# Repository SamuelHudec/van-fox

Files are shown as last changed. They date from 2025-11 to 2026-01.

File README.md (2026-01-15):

# VanFox 🦊  – Portable Air Quality Monitor for Camper Vans

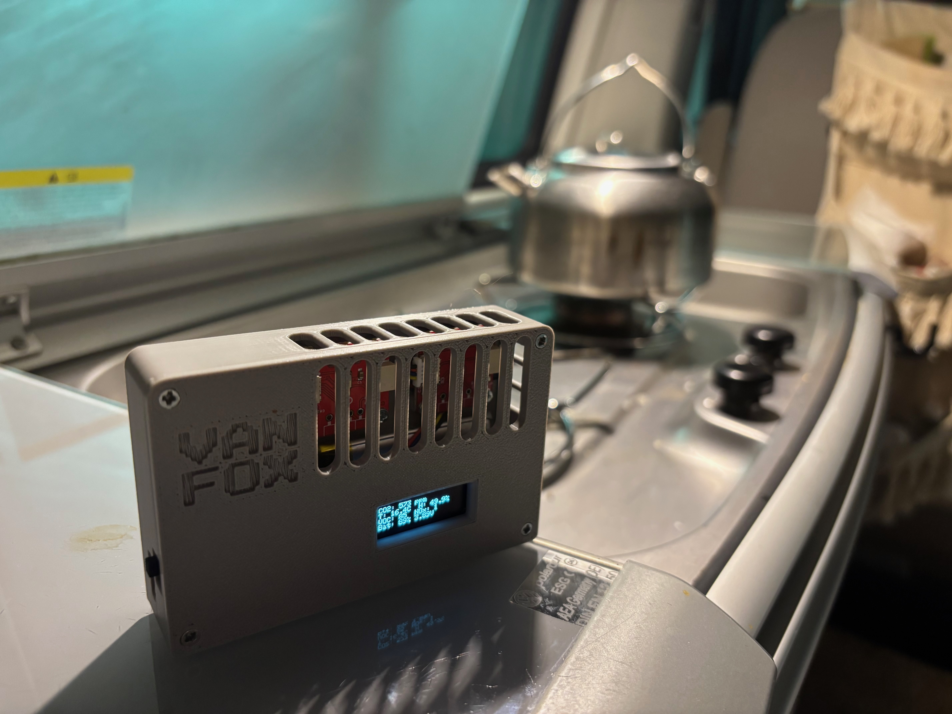
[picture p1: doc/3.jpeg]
preview


**VanFox** is a fully self-contained ESP32-C3-based air quality monitor designed for camper vans and Home Assistant.
It combines multiple environmental sensors, a motion-activated OLED display and gesture-based control.

VanFox is designed to be open, hackable and power-efficient, with a strong focus on real-world camper van usage. Thanks to the built-in battery, it can operate without external power — during off-grid camping, power outages, or when taken outside.

As a camper, I like when one device serves more than one purpose. VanFox can travel with you in your van, and when you are home, it can also be used as a stationary air quality monitor for your household.

## Assembly Guide

1. Purchase the components
	- ~298czk [ESP32 Dev Board](https://www.laskakit.cz/laskakit-microesp/)
	- ~448czk [CO2, temperature and humidity senzor](https://www.laskakit.cz/laskakit-stcc4-senzor-co2--teploty-a-vlhkosti-vzduchu/)
	- ~368czk [VOx and NOx senzor](https://www.laskakit.cz/laskakit-sgp41-voc-a-nox-senzor-kvality-ovzdusi/)
	- ~118czk [Battery](https://www.laskakit.cz/ehao-lipol-baterie-603048-900mah-3-7v/)
	- ~128czk [Oled Display](https://www.laskakit.cz/laskakit-oled-displej-128x32-0-91--i--c/)
	- ~198czk [Gyroscop](https://www.laskakit.cz/laskakit-bmi270-6-osy-gyroskop-a-akcelerometr/)
	- ~6czk [Buzz](https://www.laskakit.cz/aktivni-bzucak-3-3v/)
	- ~4czk [Switch](https://www.laskakit.cz/posuvny-prepinac-0-5a-50vdc/)
	- 4x~12czk [μŠup](https://www.laskakit.cz/--sup--stemma-qt--qwiic-jst-sh-4-pin-kabel-5cm/)
	- 10x M2 screws, I bougth a box and trimmed as needed

2. 3D print the enclosure from [3D](3D).
3. [Solder](doc/1.jpeg) the buzzer, switch, I²C cables, and battery to the ESP board. For I²C and battery, the pin placement is fixed by the board design. GPIO pins for the buzzer (GPIO 3) and switch (GPIO 2) were intentionally placed as far as possible from the USB-C connector, so the board fits properly into the enclosure.
4. Create a copy of `secrets_example.h` and rename it to `secrets.h`, then fill in all required values. 
5. Use Arduino IDE to flash the firmware to the device.
6. Home Assistant integration (optional)
	- Install the MQTT Broker add-on.
	- In the add-on configuration, add the device credentials `MQTT_NAME` and `MQTT_PASSWORD`.

There is also an option to use [ESPhome](SW/vanfox-esphome.yaml). However, gyroscope support is currently missing, which means, the display cannot be turned off automatically and will remain on continuously.

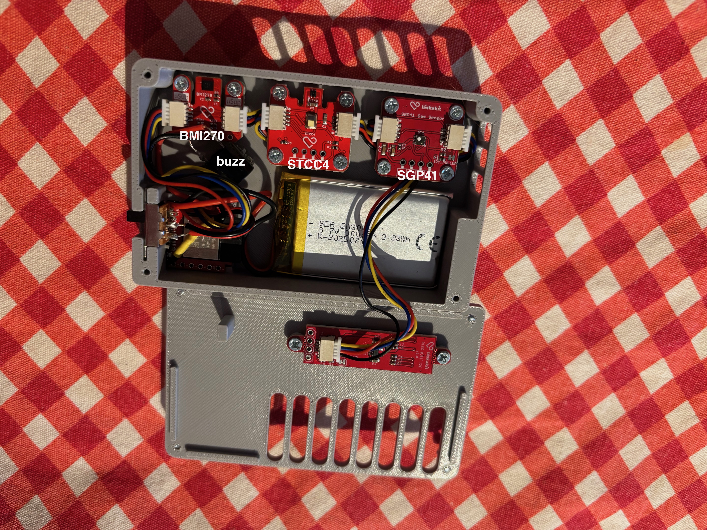
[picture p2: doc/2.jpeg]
preview2


## Operating Modes

### Power Modes (Switch-Controlled)

**Switch ON - Device Active:**
- **Home Mode** (WiFi available)
  - Connects to Home Assistant via MQTT
  - Sends sensor data
  - Display timeout: 30 seconds
- **Traveling Mode** (No WiFi)
  - Runs offline, no cloud connectivity
  - Light sleep between sensor reads (~90% power savings)
  - Display timeout: 10 seconds

**Switch OFF - Deep Sleep:**
- Ultra-low power (~10µA draw)
- Wakes every 60 seconds to check switch state
- Device boots when switch turned ON

### Display Modes (Available in Both Home & Traveling)

#### Air Quality Mode (Default)
Shows real-time environmental readings (Motion detection wakes display):
```
CO2: 412 ppm
T: 21.3°C  H: 45.7%
VOC: 102  NOx: 34
Bat: 100% (4.05V)
```

#### Level Mode (Digital Spirit Level)
Activated by **triple shake gesture**. Shows roll angle in degrees for vehicle leveling. Auto-returns to Air Quality Mode after 2 minutes

## TODO
- add boudaries for buzz

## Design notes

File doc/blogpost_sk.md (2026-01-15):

VanFox vznikol z mojej zvedavosti. S manželkou trávime veľa času v camper van a zaujímalo ma, ako sa v malom uzavretom priestore postupne zhoršuje kvalita vzduchu. Počas spánku stúpa CO₂ a pri varení sa zas hromadí vlhkosť a výpary oveľa skôr než doma v byte. Hotové riešenia možno existujú, ale ja som chcel niečo, na čom sa niečo nové naučím a bude to zábava. Navyše som chcel, aby zariadenie vedelo slúžiť nielen vo van-e, ale aj doma. Na moje prekvapenie aj manželka je nadšená.

Ako základ som si zvolil LaskaKit ESP32 mini, pretože mi v jednom riešení ponúka I²C konektivitu, nabíjanie batérie, jednoduché flashovanie kódu a možnosť reťaziť senzory pomocou uŠup konektorov. Postup zostavenia, zoznam komponentov aj 3D model krabičky som popísal na GitHube (odkaz nižšie).

Mašinka meria CO₂, teplotu, vlhkosť a kvalitu ovzdušia pomocou VOC a NOx indexov. Údaje zobrazuje na OLED displeji, ktorý sa rozsvieti len pri pohybe zariadenia. Vďaka integrovanej batérii ho možno používať ako prenosné zariadenie pri kempovaní v aute, stane atď. Zatiaľ čo doma je určený na trvalé napájanie, na cestách experimentujem s úspornými režimami a light sleep.

Gyroskop a akcelerometer som pôvodne pridal len kvôli tomu, aby sa displej rozsvietil pohybom bez potreby tlačidiel. Až neskôr som si uvedomil, že viem vyriešiť aj ďalší môj problém. Preto som pridal LEVEL MODE, digitálnu vodováhu aktivovanú trojitým zatrasením zariadenia.

Čo budeš potrebovať:
- [ESP32 dev board](https://www.laskakit.cz/laskakit-microesp/)
- [CO2, temperature and humidity senzor](https://www.laskakit.cz/laskakit-stcc4-senzor-co2--teploty-a-vlhkosti-vzduchu/)
- [VOx and NOx senzor](https://www.laskakit.cz/laskakit-sgp41-voc-a-nox-senzor-kvality-ovzdusi/)
- [Battery](https://www.laskakit.cz/ehao-lipol-baterie-603048-900mah-3-7v/)
- [Oled Display](https://www.laskakit.cz/laskakit-oled-displej-128x32-0-91--i--c/)
- [Gyroscop](https://www.laskakit.cz/laskakit-bmi270-6-osy-gyroskop-a-akcelerometr/)
- [Buzz](https://www.laskakit.cz/aktivni-bzucak-3-3v/)
- [Switch](https://www.laskakit.cz/posuvny-prepinac-0-5a-50vdc/)
- 4x [μŠup](https://www.laskakit.cz/--sup--stemma-qt--qwiic-jst-sh-4-pin-kabel-5cm/)
- 10x M2 šroub, ja som kupil celu krabičku a odštipal poldla potreby

Ako na to:
1. Vytlačte krabičku z [3D](https://github.com/SamuelHudec/van-fox/tree/main/3D).
2. Pripájkujte bzučiak, spínač, káble I²C a batériu k doske ESP. Pre I²C a batériu je umiestnenie pinov pevne stanovené dizajnom dosky. Piny GPIO pre bzučiak (GPIO 3) a spínač (GPIO 2) boli zámerne vybrané čo najďalej od konektora USB-C, aby doska správne zapadla do krytu.
3. Vytvorte kópiu súboru `secrets_example.h` a premenujte ho na `secrets.h`, potom vyplňte všetky požadované hodnoty. Nahrajte [kod](https://github.com/SamuelHudec/van-fox/blob/main/SW/vanfox/vanfox.ino).
4. Integrácia s Home Assistant (voliteľné)
- Nainštalujte doplnok MQTT Broker.
- V konfigurácii doplnku pridajte prihlasovacie údaje zariadenia `MQTT_NAME` a `MQTT_PASSWORD`.

Projekt je stále vo vývoji. Napríklad bzučiak je zapojený, ale zatiaľ sa v kóde nepoužíva. Pôvodný zámer bol zvukové upozornenie pri zhoršení kvality ovzdušia, no správanie ešte nemám úplne navrhnuté. Rovnako aj gestá, najmä triple-shake, by si zaslúžili ďalšie doladenie. V kóde je aj integrácia do Home Assistantu cez MQTT.

Ak máš nápady, chuť prispieť alebo niečo vylepšiť, som otvorený spolupráci. Napríklad, by sa prepínač dal napojiť priamo na prúd a namiesto deepsleep režimu, natvrdo vypnuť modul. Rád uvítam akékoľvek rady, či už po SW alebo HW stránke. Neboj sa rovno otvoriť PR s vylepšeniami alebo pokojne pridať aj vlastný file či rozšírenie.

https://github.com/SamuelHudec/van-fox

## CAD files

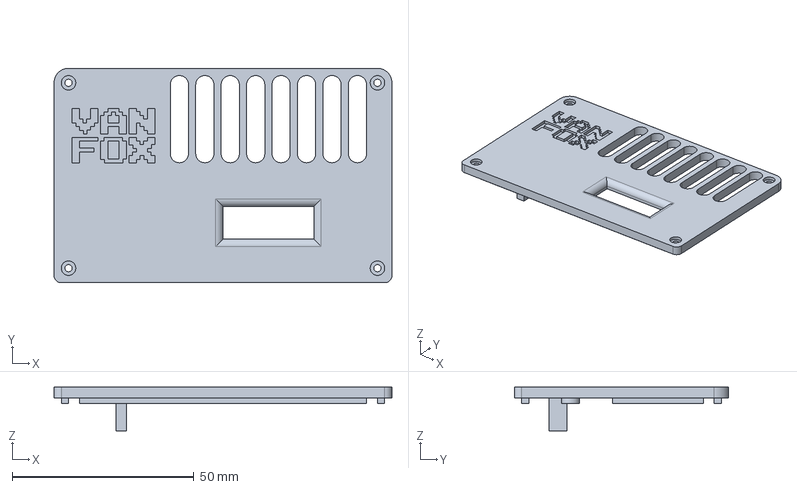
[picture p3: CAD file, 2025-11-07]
3D/hatch_V1.FCStd
93.0 x 59.0 x 12.0 mm

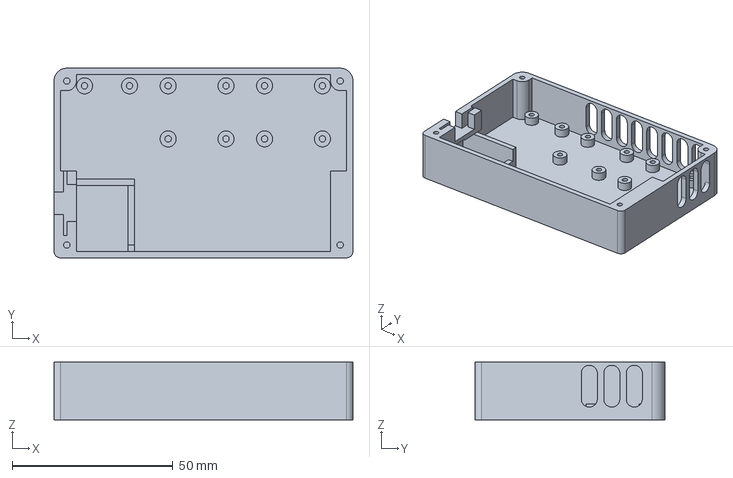
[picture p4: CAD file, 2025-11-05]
3D/box_V1.FCStd
93.0 x 59.0 x 18.0 mm

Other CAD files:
3D/box_V1.stl
3D/hatch_V1.stl

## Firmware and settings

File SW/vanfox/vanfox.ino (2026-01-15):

/*********************************************************************
 * VanFox – Portable Air Quality Monitor for Camper Vans
 * -----------------------------------------------------
 * Reads data from:
 *  - STCC4  (CO₂, Temperature, Humidity)
 *  - SGP41  (VOC, NOx)
 *  - BMI270 (Accelerometer, Gyroscope)
 *  - SSD1306 128x32 OLED Display
 *  - Battery voltage via ADC0 (LaskaKit MicroESP-C3 mini)
 *
 * Features:
 *  - Auto display sleep after inactivity
 *  - Triple-shake gesture to toggle LEVEL MODE
 *  - Level mode (digital spirit level)
 *  - Adaptive sensor/display update rates
 *********************************************************************/

#include <Wire.h>
#include <Adafruit_GFX.h>
#include <Adafruit_SSD1306.h>
#include <SensirionI2cStcc4.h>
#include <SensirionI2CSgp41.h>
#include <VOCGasIndexAlgorithm.h>
#include <NOxGasIndexAlgorithm.h>
#include "SparkFun_BMI270_Arduino_Library.h"
#include <WiFi.h>
#include <PubSubClient.h>
#include "esp_wifi.h"
#include "esp_bt.h"
#include "driver/gpio.h"
#include "driver/rtc_io.h"
#include "secrets.h"

// ===================================================================
// ---------------------- PINS CONFIG --------------------------------
#define SWITCH_PIN 2
#define BUZZ_PIN 3

// ===================================================================
// ---------------------- OLED CONFIG --------------------------------
#define SCREEN_WIDTH 128
#define SCREEN_HEIGHT 32
#define OLED_ADDR 0x3C
Adafruit_SSD1306 display(SCREEN_WIDTH, SCREEN_HEIGHT, &Wire, -1);

// ===================================================================
// ---------------------- SENSOR OBJECTS -----------------------------
SensirionI2cStcc4 stcc4;
SensirionI2CSgp41 sgp41;
VOCGasIndexAlgorithm vocAlgorithm;
NOxGasIndexAlgorithm noxAlgorithm;
BMI270 imu;

// ===================================================================
// ---------------------- WIFI & MQTT OBJECTS ------------------------
enum OperatingMode { MODE_TRAVELING, MODE_HOME };
OperatingMode currentMode = MODE_TRAVELING;
WiFiClient espClient;
PubSubClient mqtt(espClient);

// ===================================================================
// ---------------------- BATTERY CONFIG ------------------------------
#define PIN_BAT_ADC 0
#define BAT_DIVIDER_RATIO 1.7693877551  // (1M + 1.3M)

float readBatteryVoltage() {
  return analogReadMilliVolts(PIN_BAT_ADC) * BAT_DIVIDER_RATIO / 1000.0;
}

int voltageToPercent(float voltage) {
  voltage = constrain(voltage, 3.0, 4.0);
  return (int)((voltage - 3.0) * 100 / (4.0 - 3.0));
}

// ===================================================================
// ---------------------- LEVEL OFFSETS -------------------------------
const float ROLL_OFFSET  = 0.0;  // Calibration offset (adjust on level surface)

// ===================================================================
// ---------------------- GLOBAL VARIABLES ---------------------------
float co2_ppm = NAN, temperature_c = NAN, humidity_rh = NAN;
float voc_index = NAN, nox_index = NAN;
float battery_v = NAN;
int battery_p = 0;
bool charging = false;

bool displayOn = true;
bool gyroMode = false;
unsigned long lastModeSwitch = 0;

// ---------------------- TIMERS & PERIODS ---------------------------
const uint32_t MOTION_PERIOD_MS   = 100;    // IMU polling (shake + motion)
const uint32_t AIR_DISPLAY_MS     = 1000;   // redraw air screen
const uint32_t LEVEL_DISPLAY_MS   = 200;    // redraw level screen
const uint32_t AIR_SENSOR_READ_MS = 2000;   // SCD41 & SGP41 read interval
const uint32_t HOME_DISPLAY_TIMEOUT = 30000;       // 30s
const uint32_t TRAVELING_DISPLAY_TIMEOUT = 10000;  // 10s
const uint32_t HA_SEND_INTERVAL_MS = 300000;       // 5min
const uint32_t MQTT_RECONNECT_INTERVAL_MS = 60000; // 60s
const uint32_t DEEP_SLEEP_WAKEUP_SEC = 60;         // Wake every 60s to check switch

uint32_t t_motion = 0;
uint32_t t_air    = 0;
uint32_t t_level  = 0;
uint32_t t_air_sensor = 0;  // Replaces t_scd and t_sgp
uint32_t t_ha_send = 0;
uint32_t t_mqtt_reconnect = 0;

// ---------------------- ROBUST SHAKE DETECTION  ---------------------------
bool detectShake(float shakeIntensity) {
  static bool wasAbove = false;
  static unsigned long lastShake = 0;
  const float UPPER_THRESHOLD = 1.2;
  const float LOWER_THRESHOLD = 0.5;
  const int MIN_INTERVAL = 250;

  bool shakeDetected = false;

  if (!wasAbove && shakeIntensity > UPPER_THRESHOLD) {
    wasAbove = true;
  }

  if (wasAbove && shakeIntensity < LOWER_THRESHOLD) {
    wasAbove = false;
    unsigned long now = millis();
    if (now - lastShake > MIN_INTERVAL) {
      shakeDetected = true;
      lastShake = now;
    }
  }

  return shakeDetected;
}

// ===================================================================
// ---------------------- DEEP SLEEP FUNCTION ------------------------
void enterDeepSleep() {
  Serial.println("Switch OFF - entering deep sleep...");

  display.clearDisplay();
  display.setTextSize(1);
  display.setCursor(0, 10);
  display.println("Powering OFF...");
  display.println("Flip switch to wake");
  display.display();
  delay(2000);

  display.clearDisplay();
  display.display();

  // Configure timer wakeup: wake periodically to check switch state
  esp_sleep_enable_timer_wakeup(DEEP_SLEEP_WAKEUP_SEC * 1000000ULL);

  Serial.printf("Entering deep sleep (%ds wakeup)...\n", DEEP_SLEEP_WAKEUP_SEC);
  delay(100);
  esp_deep_sleep_start();
}

// ===================================================================
// ---------------------- SETUP --------------------------------------
void setup() {
  // --- Configure mode switch FIRST (before any other init) ---
  pinMode(SWITCH_PIN, INPUT_PULLUP);

  // Check if we woke from deep sleep with timer wakeup
  esp_sleep_wakeup_cause_t wakeup_reason = esp_sleep_get_wakeup_cause();

  if (wakeup_reason == ESP_SLEEP_WAKEUP_TIMER) {
    if (digitalRead(SWITCH_PIN) == LOW) {
      esp_sleep_enable_timer_wakeup(DEEP_SLEEP_WAKEUP_SEC * 1000000ULL);
      esp_deep_sleep_start();
    }
  }

  Serial.begin(115200);
  delay(1000);

  // --- Disable WiFi immediately to prevent auto-connect ---
  WiFi.persistent(false);
  WiFi.mode(WIFI_OFF);
  delay(100);

  // --- I2C Init ---
  Wire.begin(8, 10);   // SDA=8, SCL=10
  Wire.setClock(50000);

  // --- OLED Init ---
  if (!display.begin(SSD1306_SWITCHCAPVCC, OLED_ADDR)) {
    Serial.println("OLED not found!");
    while (true) delay(100);
  }
  display.clearDisplay();
  display.setTextColor(SSD1306_WHITE);
  display.setTextSize(1);
  display.println("VanFox Air Monitor");
  display.println("Initializing...");
  display.display();
  delay(1000);

  // ---------------- MODE SELECTION BASED ON SWITCH ----------------
  display.clearDisplay();
  display.setCursor(0, 0);
  display.println("VanFox Air Monitor");

  // Give WiFi hardware time to stabilize after boot
  delay(2000);

  bool switchOn = digitalRead(SWITCH_PIN) == HIGH;

  // If switch is OFF, enter deep sleep immediately (no sensor init needed)
  if (!switchOn) {
    display.println("Switch OFF - Power");
    display.println("saving mode");
    display.display();
    delay(1000);
    enterDeepSleep();
  }

  if (switchOn) {
    // Switch ON - Try HOME mode with WiFi
    Serial.println("Switch ON - attempting HOME mode");
    display.println("Switch: HOME Mode");
    display.println("Waiting 10s...");
    display.println("(router rate limit)");
    display.display();

    // Wait to let router rate-limit expire
    delay(10000);  // 10 second delay before WiFi attempt

    display.clearDisplay();
    display.setCursor(0, 0);
    display.println("Checking WiFi...");
    display.display();

    if (initWiFi()) {
      currentMode = MODE_HOME;
      display.println("WiFi Connected!");
      display.printf("IP: %s\n", WiFi.localIP().toString().c_str());
      display.display();
      delay(1000);

      if (initHomeAssistantAPI()) {
        display.println("HA: Connected");
      } else {
        display.println("HA: Failed (retry)");
      }
      display.display();
      delay(2000);
    } else {
      currentMode = MODE_TRAVELING;
      display.println("WiFi Failed!");
      display.println("Running offline");
      display.display();
      delay(2000);
    }
  }

  // ---------------- SENSOR INITIALIZATION ----------------
  bool scd_ok = false, sgp_ok = false, imu_ok = false;

  // --- STCC4 Init ---
  Serial.println("Initializing STCC4...");
  stcc4.begin(Wire, STCC4_I2C_ADDR_64);
  delay(500);
  stcc4.stopContinuousMeasurement();
  if (stcc4.startContinuousMeasurement() == 0) {
    scd_ok = true;  // Keep variable name for compatibility
    Serial.println("STCC4 ready.");
  } else {
    Serial.println("STCC4 not responding!");
  }

  // --- SGP41 Init ---
  Serial.println("Initializing SGP41...");
  sgp41.begin(Wire);
  delay(200);
  uint16_t rawVoc, rawNox;
  uint16_t dummyH = 0, dummyT = 0;
  if (sgp41.measureRawSignals(dummyH, dummyT, rawVoc, rawNox) == 0) {
    sgp_ok = true;
    Serial.println("SGP41 ready.");
  } else {
    Serial.println("SGP41 not responding!");
  }

  // --- BMI270 Init ---
  Serial.println("Initializing BMI270...");
  if (imu.beginI2C(0x68) == BMI2_OK) {
    imu_ok = true;
    Serial.println("BMI270 ready.");
  } else {
    Serial.println("BMI270 not detected!");
  }

  // ---------------- DISPLAY SENSOR STATUS ----------------
  display.clearDisplay();
  display.setCursor(0, 0);
  display.println("Sensor check:");
  display.printf("STCC4: %s\n", scd_ok ? "OK" : "FAIL");
  display.printf("SGP41: %s\n", sgp_ok ? "OK" : "FAIL");
  display.printf("BMI270: %s\n", imu_ok ? "OK" : "FAIL");

  if (scd_ok && sgp_ok && imu_ok)
    display.println("All sensors ready!");
  else
    display.println("Some sensors missing!");

  display.display();
  delay(2000);
}

// ===================================================================
// ---------------------- LOOP --------------------------------------
void loop() {
  uint32_t now = millis();

  // ============================================================
  // ------------------- MODE SWITCH CHECK ----------------------
  static uint32_t lastSwitchCheck = 0;
  static bool lastSwitchState = HIGH;

  if (now - lastSwitchCheck >= 2000) {
    lastSwitchCheck = now;
    bool currentSwitchState = digitalRead(SWITCH_PIN) == HIGH;

    // Detect switch change
    if (currentSwitchState != lastSwitchState) {
      lastSwitchState = currentSwitchState;

      if (currentSwitchState) {
        Serial.println("Switch ON - switching to HOME mode");

        display.clearDisplay();
        display.setTextSize(1);
        display.setCursor(0, 10);
        display.println("Switching to");
        display.println("HOME MODE...");
        display.display();
        delay(1000);

        if (initWiFi()) {
          currentMode = MODE_HOME;
          initHomeAssistantAPI();
          Serial.println("HOME mode activated");
        } else {
          Serial.println("WiFi failed, staying TRAVELING");
        }

      } else {
        enterDeepSleep();
      }
    }
  }

  // --- Air Quality Sensors (STCC4 + SGP41) ---
  if (now - t_air_sensor >= AIR_SENSOR_READ_MS) {
    t_air_sensor = now;

    // Read STCC4 (CO2, Temperature, Humidity)
    int16_t co2Raw;
    float temp, hum;
    uint16_t status;
    if (stcc4.readMeasurement(co2Raw, temp, hum, status) == 0) {
      co2_ppm = (float)co2Raw;  // Convert int16_t to float
      temperature_c = temp;
      humidity_rh = hum;
    }

    // Read SGP41 (VOC, NOx) - uses temp/humidity from STCC4 for compensation
    uint16_t compHumidity = (uint16_t)((humidity_rh * 65535) / 100);
    uint16_t compTemperature = (uint16_t)(((temperature_c + 45) * 65535) / 175);
    uint16_t rawVoc = 0, rawNox = 0;
    if (sgp41.measureRawSignals(compHumidity, compTemperature, rawVoc, rawNox) == 0) {
      voc_index = vocAlgorithm.process(rawVoc);
      nox_index = noxAlgorithm.process(rawNox);
    }
  }

  // --- Battery ---
  static float smoothBatteryV = 0.0;
  battery_v = readBatteryVoltage();
  smoothBatteryV = 0.9f * smoothBatteryV + 0.1f * battery_v;
  battery_p = voltageToPercent(smoothBatteryV);

  // ============================================================
  // ------------------- MQTT HANDLING (HOME MODE) --------------
  if (currentMode == MODE_HOME) {
    if (mqtt.connected()) {
      mqtt.loop();
      if (now - t_ha_send >= HA_SEND_INTERVAL_MS) {
        t_ha_send = now;
        sendDataToHomeAssistant();
      }
    } else {
      if (now - t_mqtt_reconnect >= MQTT_RECONNECT_INTERVAL_MS) {
        t_mqtt_reconnect = now;
        Serial.println("Reconnecting to MQTT...");
        if (WiFi.status() != WL_CONNECTED) {
          Serial.println("WiFi disconnected - reconnecting...");
          WiFi.disconnect();
          WiFi.begin(WIFI_SSID, WIFI_PASSWORD);

          unsigned long startAttempt = millis();
          while (WiFi.status() != WL_CONNECTED && millis() - startAttempt < 10000) {
            delay(500);
          }

          if (WiFi.status() != WL_CONNECTED) {
            Serial.println("WiFi reconnect failed");
            return;
          }
          Serial.println("WiFi reconnected!");
        }
        if (mqtt.connect("vanfox", "vanfox", "vanfox97411")) {
          Serial.println("MQTT reconnected");
          publishDiscoveryConfig();
        } else {
          Serial.print("MQTT reconnect failed, rc=");
          Serial.println(mqtt.state());
        }
      }
    }
  }

  // ============================================================
  // ------------------- Motion / Shake polling -----------------
  if (now - t_motion >= MOTION_PERIOD_MS) {
    t_motion = now;

    if (imu.getSensorData() == BMI2_OK) {
      float accMagnitude = sqrt(
        imu.data.accelX * imu.data.accelX +
        imu.data.accelY * imu.data.accelY +
        imu.data.accelZ * imu.data.accelZ
      );

        float gyroMagnitude = sqrt(
        imu.data.gyroX * imu.data.gyroX +
        imu.data.gyroY * imu.data.gyroY +
        imu.data.gyroZ * imu.data.gyroZ
      );

      float shakeIntensity = (accMagnitude - 1.0f) * 2.0f + (gyroMagnitude / 500.0f);
      Serial.printf("acc=%.2f g  gyro=%.1f °/s  shake=%.2f\n",
                accMagnitude, gyroMagnitude, shakeIntensity);

      // --- Display move detection ---
      static unsigned long lastMotionTime = millis();
      if (accMagnitude > 1.05 && accMagnitude < 3.0) {
        lastMotionTime = millis();
        if (!displayOn && !gyroMode) {
          displayOn = true;
          Serial.println("Motion detected → display ON");
        }
      }

      // Display timeout based on mode
      uint32_t displayTimeout = (currentMode == MODE_HOME) ?
                                HOME_DISPLAY_TIMEOUT : TRAVELING_DISPLAY_TIMEOUT;

      if (!gyroMode && displayOn && millis() - lastMotionTime > displayTimeout) {
        displayOn = false;
        display.clearDisplay();
        display.display();
        Serial.printf("No motion → display OFF (%s mode)\n",
                     currentMode == MODE_HOME ? "HOME" : "TRAVELING");
      }

      // --- Triple shake ---
      static int shakeCount = 0;
      static unsigned long lastShakeTime = 0;

      if (detectShake(shakeIntensity)) {
        shakeCount++;
        lastShakeTime = millis();
        Serial.printf("Shake %d detected\n", shakeCount);
      }

      if (millis() - lastShakeTime > 2000) shakeCount = 0;  // reset after 2 sec

      if (shakeCount >= 3) {
        shakeCount = 0;
        gyroMode = !gyroMode;
        displayOn = true;
        lastModeSwitch = millis();

        display.clearDisplay();
        display.setTextSize(1);
        display.setCursor(0, 10);
        if (gyroMode) {
          display.println("Switching to");
          display.println("LEVEL MODE...");
          Serial.println("Triple shake → LEVEL MODE ON");
        } else {
          display.println("Switching to");
          display.println("AIR MODE...");
          Serial.println("Triple shake → AIR MODE OFF");
        }
        display.display();
        delay(1500);
      }
    }
  }
  
  // ============================================================
  // --- Automatic exit from LEVEL MODE after 2 minutes ---
  if (gyroMode && (millis() - lastModeSwitch > 120000)) {  // 2 min = 120000 ms
    gyroMode = false;
    displayOn = true;
    Serial.println("LEVEL MODE timeout → back to AIR MODE");

    display.clearDisplay();
    display.setTextSize(1);
    display.setCursor(0, 10);
    display.println("Timeout expired");
    display.println("--> AIR MODE");
    display.display();
    delay(1000);
  }

  // ============================================================
  // ------------------- DISPLAY UPDATE -------------------------
  if (displayOn) {
    if (!gyroMode && (now - t_air >= AIR_DISPLAY_MS)) {
      t_air = now;
      display.clearDisplay();
      display.setTextSize(1);
      display.setCursor(0, 0);
      display.printf("CO2: %.0f ppm\n", co2_ppm);
      display.printf("T: %.1fC  H: %.1f%%\n", temperature_c, humidity_rh);
      display.printf("VOC: %.0f  NOx: %.0f\n", voc_index, nox_index);

      // Status line shows mode and connection status
      if (currentMode == MODE_HOME) {
        if (mqtt.connected()) {
          display.print("Connected to HA");
        } else if (WiFi.status() == WL_CONNECTED) {
          display.print("Home MQTT ERR");
        } else {
          display.print("Home WiFi LOST");
        }
      } else {
        display.printf("Bat: %d%% %.2fV", battery_p, battery_v);
      }
      display.display();
    }

    if (gyroMode && (now - t_level >= LEVEL_DISPLAY_MS)) {
      t_level = now;
      imu.getSensorData();
      float roll = atan2(imu.data.accelY,
                         sqrt(imu.data.accelX * imu.data.accelX + imu.data.accelZ * imu.data.accelZ))
                   * 180.0 / PI;

      // Apply calibration offset
      roll += ROLL_OFFSET;
      static float smoothRoll = roll;
      smoothRoll = 0.7f * smoothRoll + 0.3f * roll;

      display.clearDisplay();
      display.setTextSize(2);
      display.setCursor(20, 10);
      display.printf("%.1f", smoothRoll);
      display.display();
    }
  }

  // ============================================================
  // ------------------- POWER MANAGEMENT ------------------------
  if (currentMode == MODE_HOME) {
    // HOME mode: No light sleep (WiFi needs to stay active)
    delay(50);
  } else {  // TRAVELING mode
    // Enable light sleep with 50ms timer wakeup for power savings
    esp_sleep_enable_timer_wakeup(50 * 1000);
    esp_light_sleep_start();
  }
}

// ===================================================================
// ---------------------- WIFI FUNCTIONS -----------------------------
bool initWiFi() {
  Serial.println("Attempting WiFi connection...");
  WiFi.disconnect(true);
  WiFi.mode(WIFI_OFF);
  delay(3000);  // Wait 1 second for router rate-limit to clear

  WiFi.setAutoReconnect(false);
  WiFi.persistent(false);

  // Now start fresh connection
  WiFi.mode(WIFI_STA);
  WiFi.begin(WIFI_SSID, WIFI_PASSWORD);

  unsigned long start = millis();
  while (WiFi.status() != WL_CONNECTED && millis() - start < 20000) {
    delay(500);
    Serial.print(".");
  }

  if (WiFi.status() == WL_CONNECTED) {
    WiFi.setSleep(WIFI_PS_MIN_MODEM);
    Serial.println("\nWiFi connected!");
    Serial.print("IP address: ");
    Serial.println(WiFi.localIP());
    Serial.print("RSSI: ");
    Serial.println(WiFi.RSSI());
    return true;
  }

  Serial.println("\nWiFi connection failed!");
  WiFi.disconnect(true);
  WiFi.mode(WIFI_OFF);
  return false;
}

// ===================================================================
// ---------------------- MQTT FUNCTIONS -----------------------------
bool initHomeAssistantAPI() {
  Serial.println("Connecting to MQTT broker...");
  Serial.print("Server: ");
  Serial.print(MQTT_SERVER);
  Serial.print(":");
  Serial.println(MQTT_PORT);

  mqtt.setServer(MQTT_SERVER, MQTT_PORT);
  mqtt.setBufferSize(512);
  mqtt.setKeepAlive(60);

  int retries = 3;
  while (retries > 0 && !mqtt.connected()) {
    Serial.print("MQTT attempt ");
    Serial.print(4 - retries);
    Serial.print("... ");

    if (mqtt.connect("vanfox", MQTT_NAME, MQTT_PASSWORD)) {
      Serial.println("connected!");
      publishDiscoveryConfig();
      return true;
    } else {
      Serial.print("failed, rc=");
      Serial.print(mqtt.state());
      Serial.print(" - ");
      // Decode error code
      switch(mqtt.state()) {
        case -4: Serial.println("Connection timeout"); break;
        case -3: Serial.println("Connection lost"); break;
        case -2: Serial.println("Connect failed"); break;
        case -1: Serial.println("Disconnected"); break;
        case 1: Serial.println("Bad protocol"); break;
        case 2: Serial.println("Bad client ID"); break;
        case 3: Serial.println("Server unavailable"); break;
        case 4: Serial.println("Bad credentials"); break;
        case 5: Serial.println("Unauthorized"); break;
        default: Serial.println("Unknown error"); break;
      }
      retries--;
      delay(2000);
    }
  }

  Serial.println("MQTT connection failed - will retry in loop");
  return false;
}
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

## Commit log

2025-10-19 3D polishing
    [box_V1.FCStd, box_V1.step, box_V1.stl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]
2025-11-05 v1 3D model
    [box_V1.FCStd, box_V1.step, box_V1.stl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]
2025-11-07 hatch corrections
    [hatch_V1.FCStd, hatch_V1.stl]
2025-11-07 hatch corrections vol2
    [hatch_V1.stl]
2025-12-31 switch pin update
2025-12-31 buzz pin
